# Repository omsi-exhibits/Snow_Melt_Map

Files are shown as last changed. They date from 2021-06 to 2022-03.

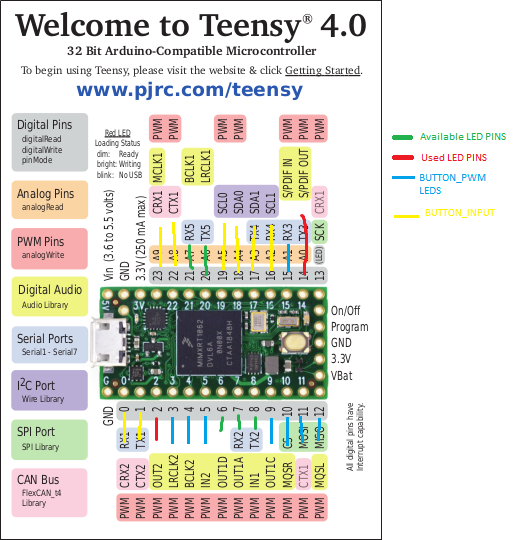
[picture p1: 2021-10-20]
docs/TEENSY_PINOUT_teensy40_card10a_rev2.png

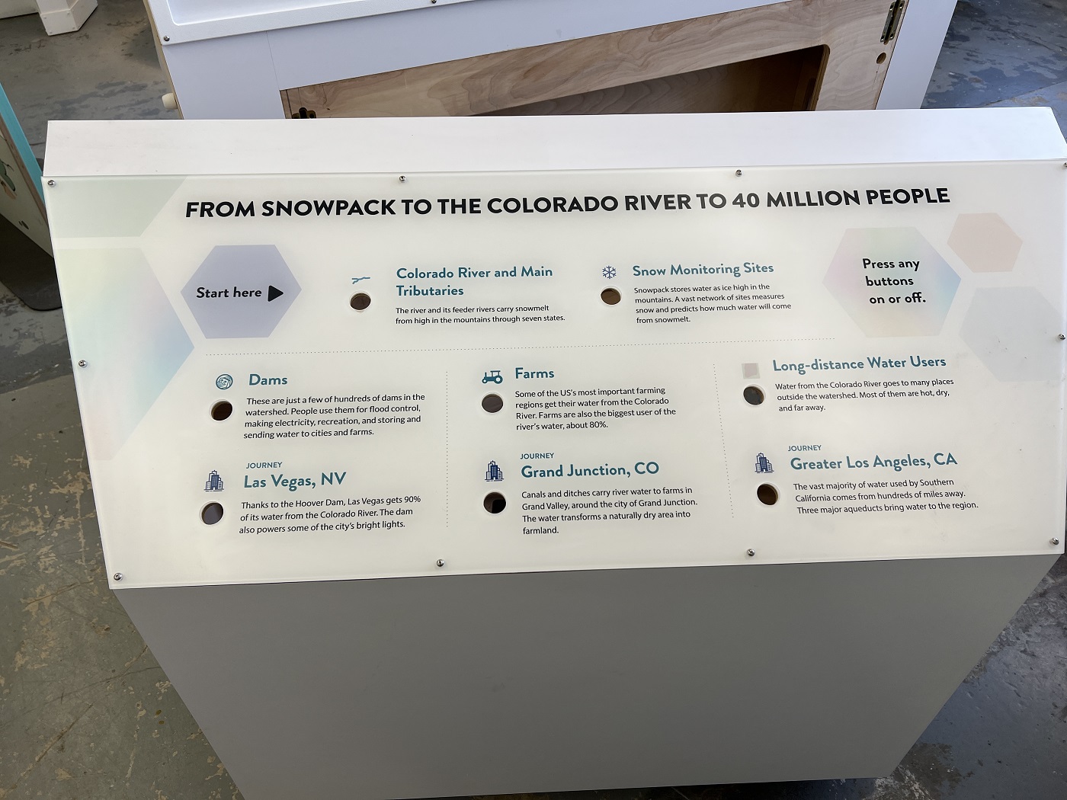
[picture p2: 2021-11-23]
docs/Button Copy.JPG

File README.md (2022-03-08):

# Snow Melt Map Notes
The electronics consist of a custom button controller pcb titled 8x_button_io_board that sends button press
commands to a octoWS2811 adapter with a teensy 4.0 socketed in it. The data sent over serial hand twisted
cable that is around 7 feet long. At a baud rate of 9600. 

addressable rgb led channels with a mcu to control the leds. The current mcu is Adafruit ItsyBitsy M0 express
with a plan to switch to a Teensy 4.0 if more pins or processing power is needed.

## Folder organization
- pcb :: contains eagle pcb files: 8x_button_io_board
- src :: main source code for the led controller 
- docs :: documentation, system diagram, map_led_hole numbering, river_segment_indexes, data sheets
- button_controller_arduino :: code for the button controller
- audio :: audio assets to be used with the wavTrigger board
- examples_tests :: quick tests used to guide prototype direction

## Led Lights
WS2813B  WS2812 code compatible. These leds have 2 data channels incase one led breaks the
backup data channel will be used. This allows the strip to skip a bad led and continue.

## Power Calculations
550 leds 48ma each LED when light at max. The led strings come in 50 led segments. We need power injection every 50 leds at least.
So that is 11 + 1 the end of the strip. 50 Leds at 48mA is 2.4A.

### Total Max Power usage
550 leds * 48mA = 26400mA, If all the leds are on at full brightness.
Power supply is a LRS-200-5 5v 200W output
(Wire Ampacity) [https://en.wikipedia.org/wiki/American_wire_gauge#Tables_of_AWG_wire_sizes]

### Fused Power distro board
(falcon f-8 power distro board) [https://www.pixelcontroller.com/store/accessories/46-f8-distro.html]
There are two power distribution boards with 8 5A fuse holders. The fuse holders take mini blade ATX fuses.

Useful fuse links
(all about fuses for led projects) [https://www.doityourselfchristmas.com/wiki/index.php?title=Power_Supplies#Using_Fuses_and_Fuseholders]
(assorted fuses) [https://www.amazon.com/Bussmann-NO-43-Blade-Tester-Puller/dp/B000DCN9BW]
(fuse holder board mount) [https://www.keyelco.com/product.cfm/Mini-Auto-Fuse-Holders/3544-2/product_id/1376]
(fuse holder mini ATM) [https://www.digikey.com/en/products/detail/keystone-electronics/3568/2137306]

# SNOW MELT MAP Button Target Areas
// Button 1 - Colorado R. & Tributaries
// --- R14 - R34
// Button 2 - Snow Monitoring Sites
// Button 3 - Dams (7)
// Button 4 - Los Vegas City, Dams, and river segments feeding Los Vegas. 
// --- R14 - R30 light up & 4 Dams (Lighting up Damns seems wrong, but maybe okay)
// Button 5 - Farms
// Button 6 - Grand Junction City, Dam, and rivers to the right of the city leading into it
// --- R21b (sub segment) (0-12leds) & R22, Dam
// Button 7 - Greater Los Angeles water supply
// --- Aqueducts too
// --- All river supply. exclude R34
// Button 8 -  (Long-distance water users) Outside Colorado r. Watershed
// --- All Water supply areas.

Once a button is pressed  - Only 1 button may be active at a time.
UI - dim all the currently lit segments and lights then activate what was pressed
Good opportunity for a fade in and fade out sound.

If the on button is pressed it turns the feature off.
If left on after a set time it can return to attractor mode. 

## Programing Notes
LedSegment defines a segment of leds, and their connection point to others.
LedRegion collects LedSegments and has state. The LedRegion can be interacted with.
- TurnedOn, TurnedOff, RiverOn, RiverOff.
- LedModule(Segment) that are for the Dams, etc. Should not store color data in their object.

## FastLED notes:
Colors are always dimmed down by a fraction. The dimming fraction is expressed in 256ths, so if you wanted to dim a color down by 25% of its current brightness, you first have to express that in 256ths. In this case, 25% = 64/256.
```cpp
  // Dim a color by 25% (64/256ths)
  // using "video" scaling, meaning: never fading to full black
  leds[i].fadeLightBy( 64 );
```
The library also provides a function that lets you 'clamp' each of the RGB channels to be within given minimums and maximums. 

Blending colors amountOfP2 is 0 - 255. 128 is 50% 255 is 100 color p2.
```cpp 
CRGB 	blend (const CRGB &p1, const CRGB &p2, fract8 amountOfP2)
```

## Hardware Purchased:
[WS2813 LEDs from raywu](https://www.aliexpress.com/item/32733155461.html)
[Aliexpress Neopixel store - Ray Wu](https://www.aliexpress.com/store/701799?spm=a2g0o.detail.1000002.2.75cff4f3j9F8uI)
LRS-200-5

## LED quality testing
I have determined that the last batch of hardware had some defects that likely were contributing to the intermittent problems
with leds flickering and possible temperature based issues.
We ordered more led strands to try to solve the issue. This time we got about 2x the leds we will need incase we run into the
same issues and need to pick the best leds from the pack.

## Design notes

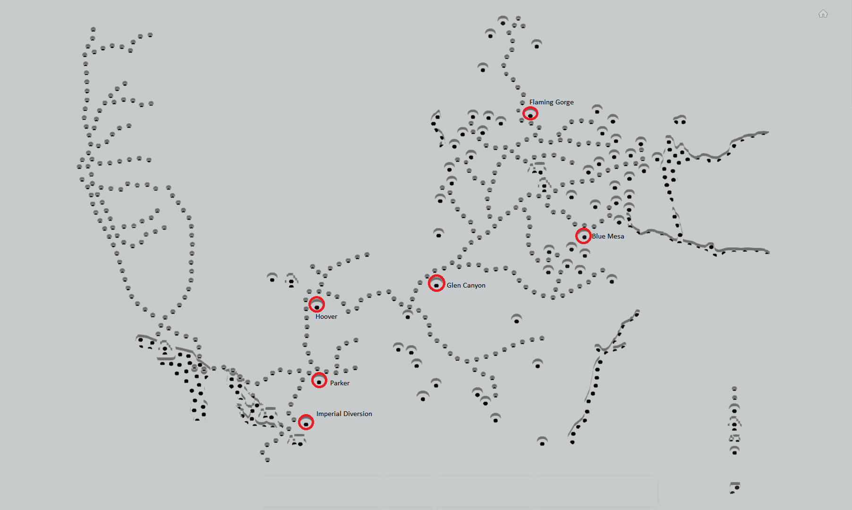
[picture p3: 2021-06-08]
docs/Map_LED_Holes_Dams.png

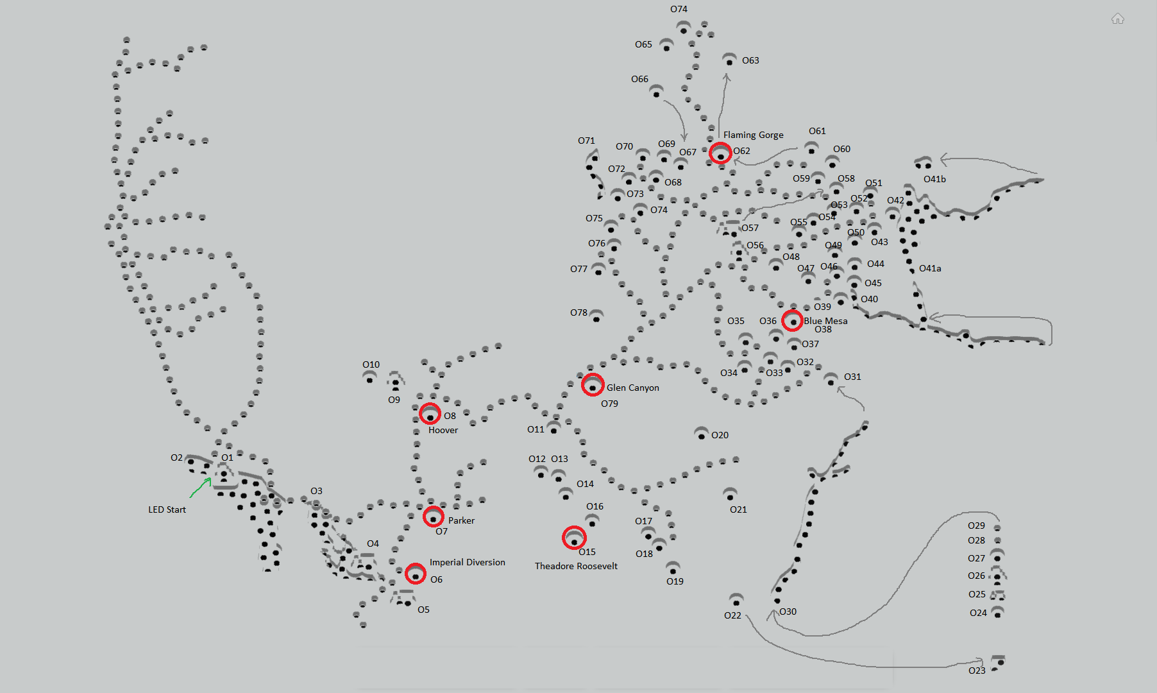
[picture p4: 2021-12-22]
docs/Map_LED_Holes_Dams_and_Rest.png

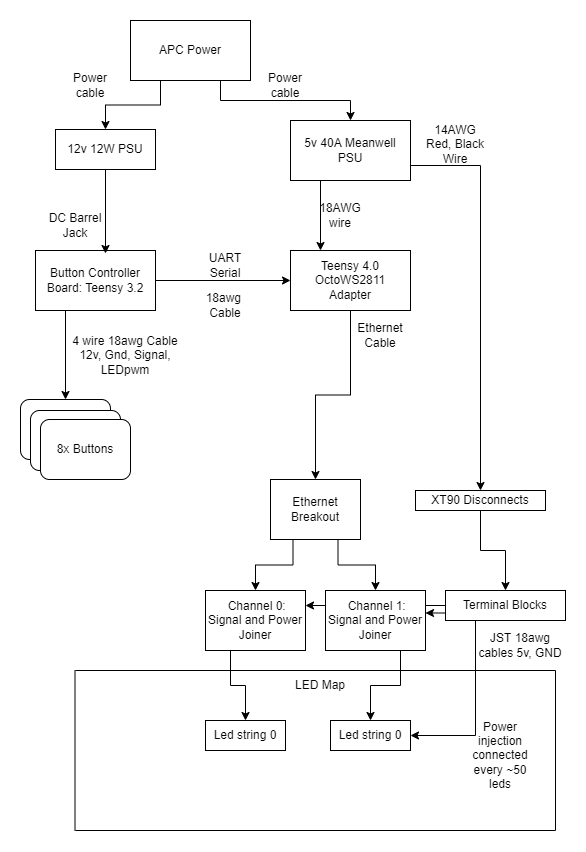
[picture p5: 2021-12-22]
docs/System Diagram.png

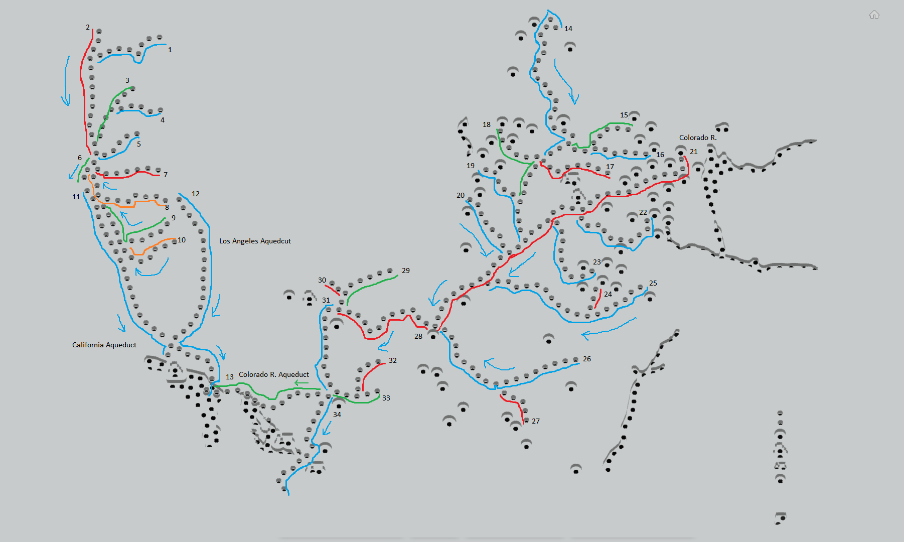
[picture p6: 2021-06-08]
docs/Map_LED_Holes_Rivers_Numbered.png

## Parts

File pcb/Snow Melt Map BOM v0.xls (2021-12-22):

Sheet: Bom
Project Name: Brain Basics | Electronics
 | Bill of Materials
ITEM | DESCRIPTION | Qty/Unit | QTY Total | UNIT PRICE | SUBTOTAL | Link | Notes
Microcontroller | Adafruit itsybitsy 32u4 5v 16mhz | 1 | 4 | $9.95 | $39.80 | https://www.digikey.com/short/zjwf45 | Ordered
12v Power Supply | LRS-100-12 AC to DC 12V 8.5A | 1 | 4 | $18.56 | $74.24 | https://www.digikey.com/products/en?keywords=LRS-100-12 | Ordered
LED strips | 5m White LED Strip Light - Radiant Series LED Tape Light – 12V, 10mm width |  | 3 | $49.95 | $149.85 | https://www.superbrightleds.com/moreinfo/flexible-led-strip-lights/5m-white-led-strip-light-radiant-series-led-tape-light-12v24v-ip20/5147/11527/ | Ordered
LED strip channels | 11Meters needed, OMSI stock is enough |  | 0 | $67.01 | $0.00 | https://www.amazon.com/hunhun-Aluminum-Mounting-Installations-Installation/dp/B07F923CXW | Omsi stock
LED strip channel clips | Clips to hold aluminum channel |  | 2 | $10.00 | $20.00 | https://www.amazon.com/15-Pack-Mounting-Aluminum-Channel-channel/dp/B07886RKNV | Ordered
Jumbo White Button | JUMBO IPB WHITE CLR CAP 14V161 LMP .250 MS W/LOCKING LMPHLDR |  | 3 | $9.95 | $29.85 | https://www.digikey.com/products/en?mpart=1187&v=1528 | Ordered
Large Red Button | RED LARGE 60mm ROUND IPB LAMP W/ .250 MICROSWITCH #161 |  | 2 | $5.95 | $11.90 | https://www.digikey.com/products/en?mpart=1190&v=1528 | Ordered
Audio Board – Wav Trigger | Wav Trig WIG-13660 |  | 3 | $51.95 | $155.85 | https://www.digikey.com/product-detail/en/sparkfun-electronics/WIG-13660/1568-1115-ND/5318757 | Ordered
Audio Amplifier | Lepy LP-2020A |  | 3 | $24.39 | $73.17 | https://www.amazon.com/Lepy-LP-2020A-Digital-Amplifier-Stereo/dp/B00C2P61FO | Ordered
Audio Cable | 3.5mm standard aux cable |  | 3 | $2.43 | $7.29 | https://www.digikey.com/product-detail/en/cnc-tech/770-10040-00100/1175-1449-ND/3828718 | Ordered
Audio Speaker | Poly-Planar MA3013G Round Flush Mount Speaker Pair, Gray, 3-Inch |  | 3 | $41.00 | $123.00 | https://www.amazon.com/Poly-Planar-3-Inch-Round-Flush-Speakers/dp/B00197V836 | Ordered
SD Card | SD card for audio board – pack of 5 |  | 1 | $22.65 | $22.65 | https://www.amazon.com/Pack-SanDisk-Memory-SDSDUNB-016G-GN3IN-Wholesale/dp/B01IMKEMC6?cv_ct_cx=sd+card | Ordered
Smart Tint Film |  |  | 1 |  | $0.00
Smart Tint Film Power supply |  |  | 1 |  | $0.00
Custom PCB | Custom PCB set of 5 |  | 1 | $50.00 | $50.00
PCB enclosure | From aliexpress - ~1month shipping AK-P-25 PLC – set of 4 |  | 1 | $35.33 | $35.33 | https://www.aliexpress.com/item/32868993859.html | Ordered 9-15ish-20
PCB components (Estimate) |  |  | 1 | $100.00 | $100.00
 |  |  |  |  | $853.13

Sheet: PCB BOM
Project Name: Snow Melt Map | Ver 0 | Updated 11-8-21 |  | Electronics
 |  |  |  | PCB Bill of Materials
ITEM | Designator | Value | Part Num | DESCRIPTION | Qty/Unit | QTY Total | UNIT PRICE | SUBTOTAL | Link | Purchase State | Notes
Power Jack | 12VOLT | x |  | DC Power Jack PTH | 1
Capacitor | C2 | 1000uF 35V | 493-1065-ND (https://www.digikey.com/en/products/detail/nichicon/UVR1E102MPD/588806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) |  | 1 |  |  |  | https://www.digikey.com/en/products/detail/nichicon/UVR1E102MPD/588806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 | omsi stock
Capacitor | C3 | 100uF 35V | UVR1E101MED (https://www.digikey.com/en/products/detail/nichicon/UVR1E101MED/588802) |  | 1 |  |  |  | https://www.digikey.com/en/products/detail/nichicon/UVR1E101MED/588802
Capacitor | C4 | 10uF 35V |  |  | 1 |  |  |  | https://www.digikey.com/en/products/detail/nichicon/UVR1E101MED/588802
LED | D1, D2 | LED Red | LTST-C150CKT (https://www.digikey.com/product-detail/en/lite-on-inc/LTST-C150CKT/160-1167-1-ND/269239) | 1206 SMT LED | 2 |  |  |  | LTST-C150CKT (https://www.digikey.com/product-detail/en/lite-on-inc/LTST-C150CKT/160-1167-1-ND/269239)
LED | D3, D4, D5, D6, D7, D8, D9, D10 | LED Green | LTST-C230GKT | 1206 SMT LED | 8
Mosfet Nch | Q2, Q4, Q5, Q6, Q7, Q8, Q9, Q10 | IRLML6344TRPBF | NCH-IRLML6344TRPBF | SOT23-3 Nch Mosfet | 8 |  |  |  | https://www.mouser.com/ProductDetail/Infineon-IR/IRLML6344TRPBF
Resistor | R3, R4, R8, R11, R21, R22, R26, R29, R31, R32, R36, R39, R41, R42, R46, R49 | 10k |  | Resistor 0805 | 16 |  |  |  |  | omsi stock
Resistor | R9, R12, R27, R30, R37, R40, R47, R50 | 100 |  | Resistor 0805 | 8 |  |  |  |  | omsi stock
Resistor | R5, R6, R7, R10, R23, R24, R25, R28, R33, R34, R35, R38, R43, R44, R45, R48 | 220 |  | Resistor 0805 | 16 |  |  |  |  | omsi stock
Resistor | R1 | 340 |  | Resistor 0805 | 1 |  |  |  |  | omsi stock
Resistor | R2 | 600 |  | Resistor 0805 | 1 |  |  |  |  | omsi stock
Power Converter 5V | U2 | R-78E5.0-1.0 | R-78E5.0-1.0 | Recom Power 5V 1A DC/ DC Converter | 1
Microcontroller 3.3V | U$1 | Teensy 3.2 |  |  | 1 |  | $20.00
Opto-Isolator | U1, U3, U4, U5 | ILD213T | ILD213T | Dual Channel Phototransistor Optocoupler | 4
Phoenix Connector Block | X1 | MSTBA3 |  | TERM BLOCK PLUG 3POS STR 5.08MM |  |  |  |  |  | omsi stock
Phoenix Connector Block | X2 | MSTBA4 |  | TERM BLOCK PLUG 4POS STR 5.08MM |  |  |  |  |  | omsi stock
Phoenix Connector Header | J7, J8, J10, J11, J13, J14, J16, J17 | CONN_043.5MM_RA | 1844236 | TERM BLOCK HDR 4POS STR 3.5MM |  |  | $1.86 |  | https://www.digikey.com/en/products/detail/phoenix-contact/1844236/349197
Phoenix Connector Plug | x | x | 1840382 | TERM BLOCK PLUG 4POS STR 3.5MM |  |  | $5.26 |  | https://www.digikey.com/en/products/detail/phoenix-contact/1840382/349179
Power Supply |  | 12v 1A |  | 12v 1A 2.1 ID x 5.5 OD | 1 | 1 | $13.00 |  | https://www.digikey.com/en/products/detail/cui-inc/SWI12-12-N-P5R/5287240 | omsi stock
Enclosure |  |  | SZMOK AK-P-25 Enclosure |  |  |  |  |  | https://www.aliexpress.com/item/32868993859.html
Screws |  |  |  | #4 1/2” screws w/ lock washer |  |  |  |  |  | omsi stock

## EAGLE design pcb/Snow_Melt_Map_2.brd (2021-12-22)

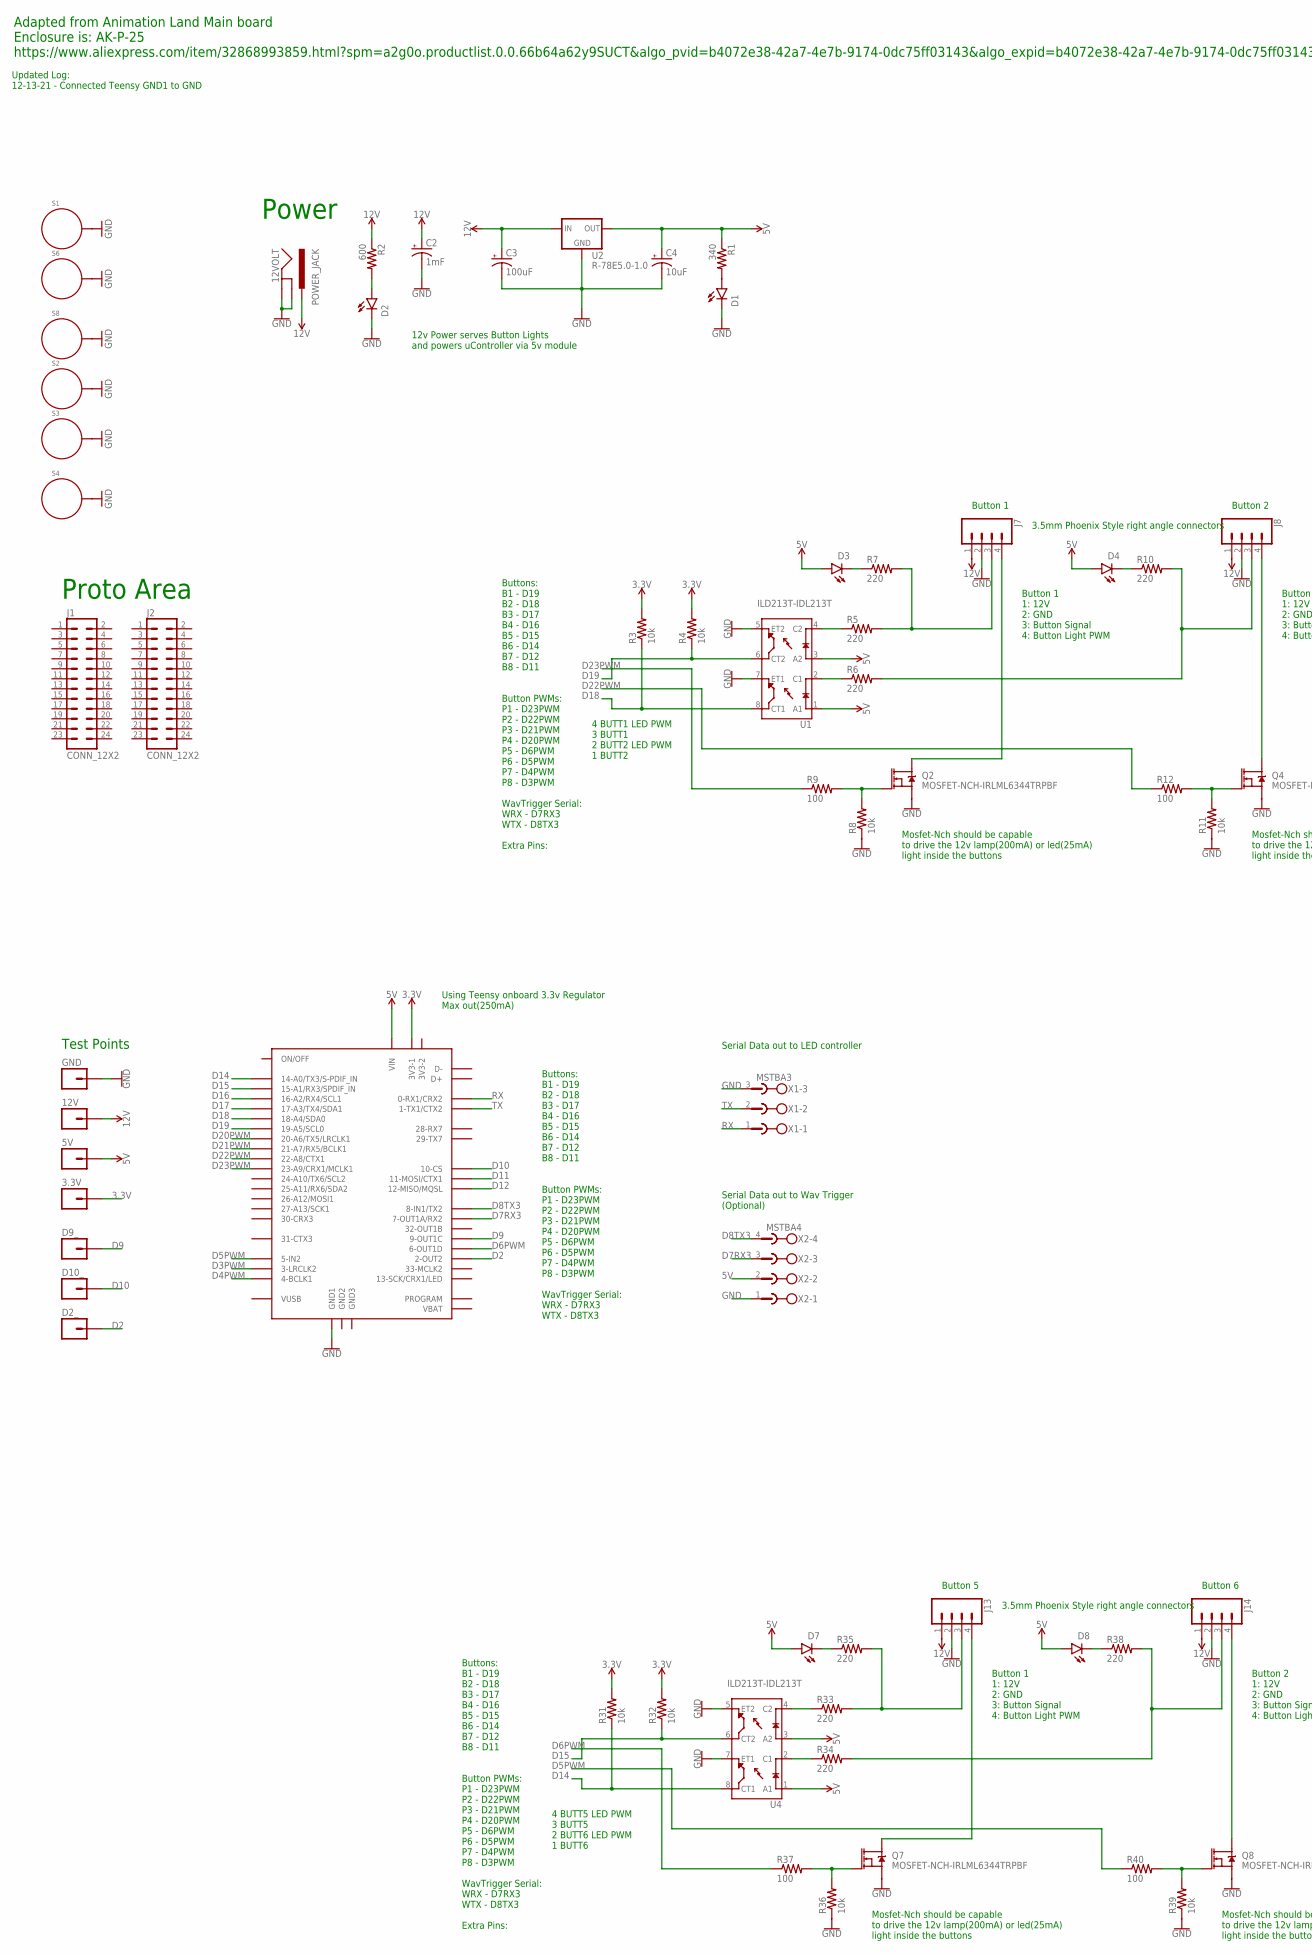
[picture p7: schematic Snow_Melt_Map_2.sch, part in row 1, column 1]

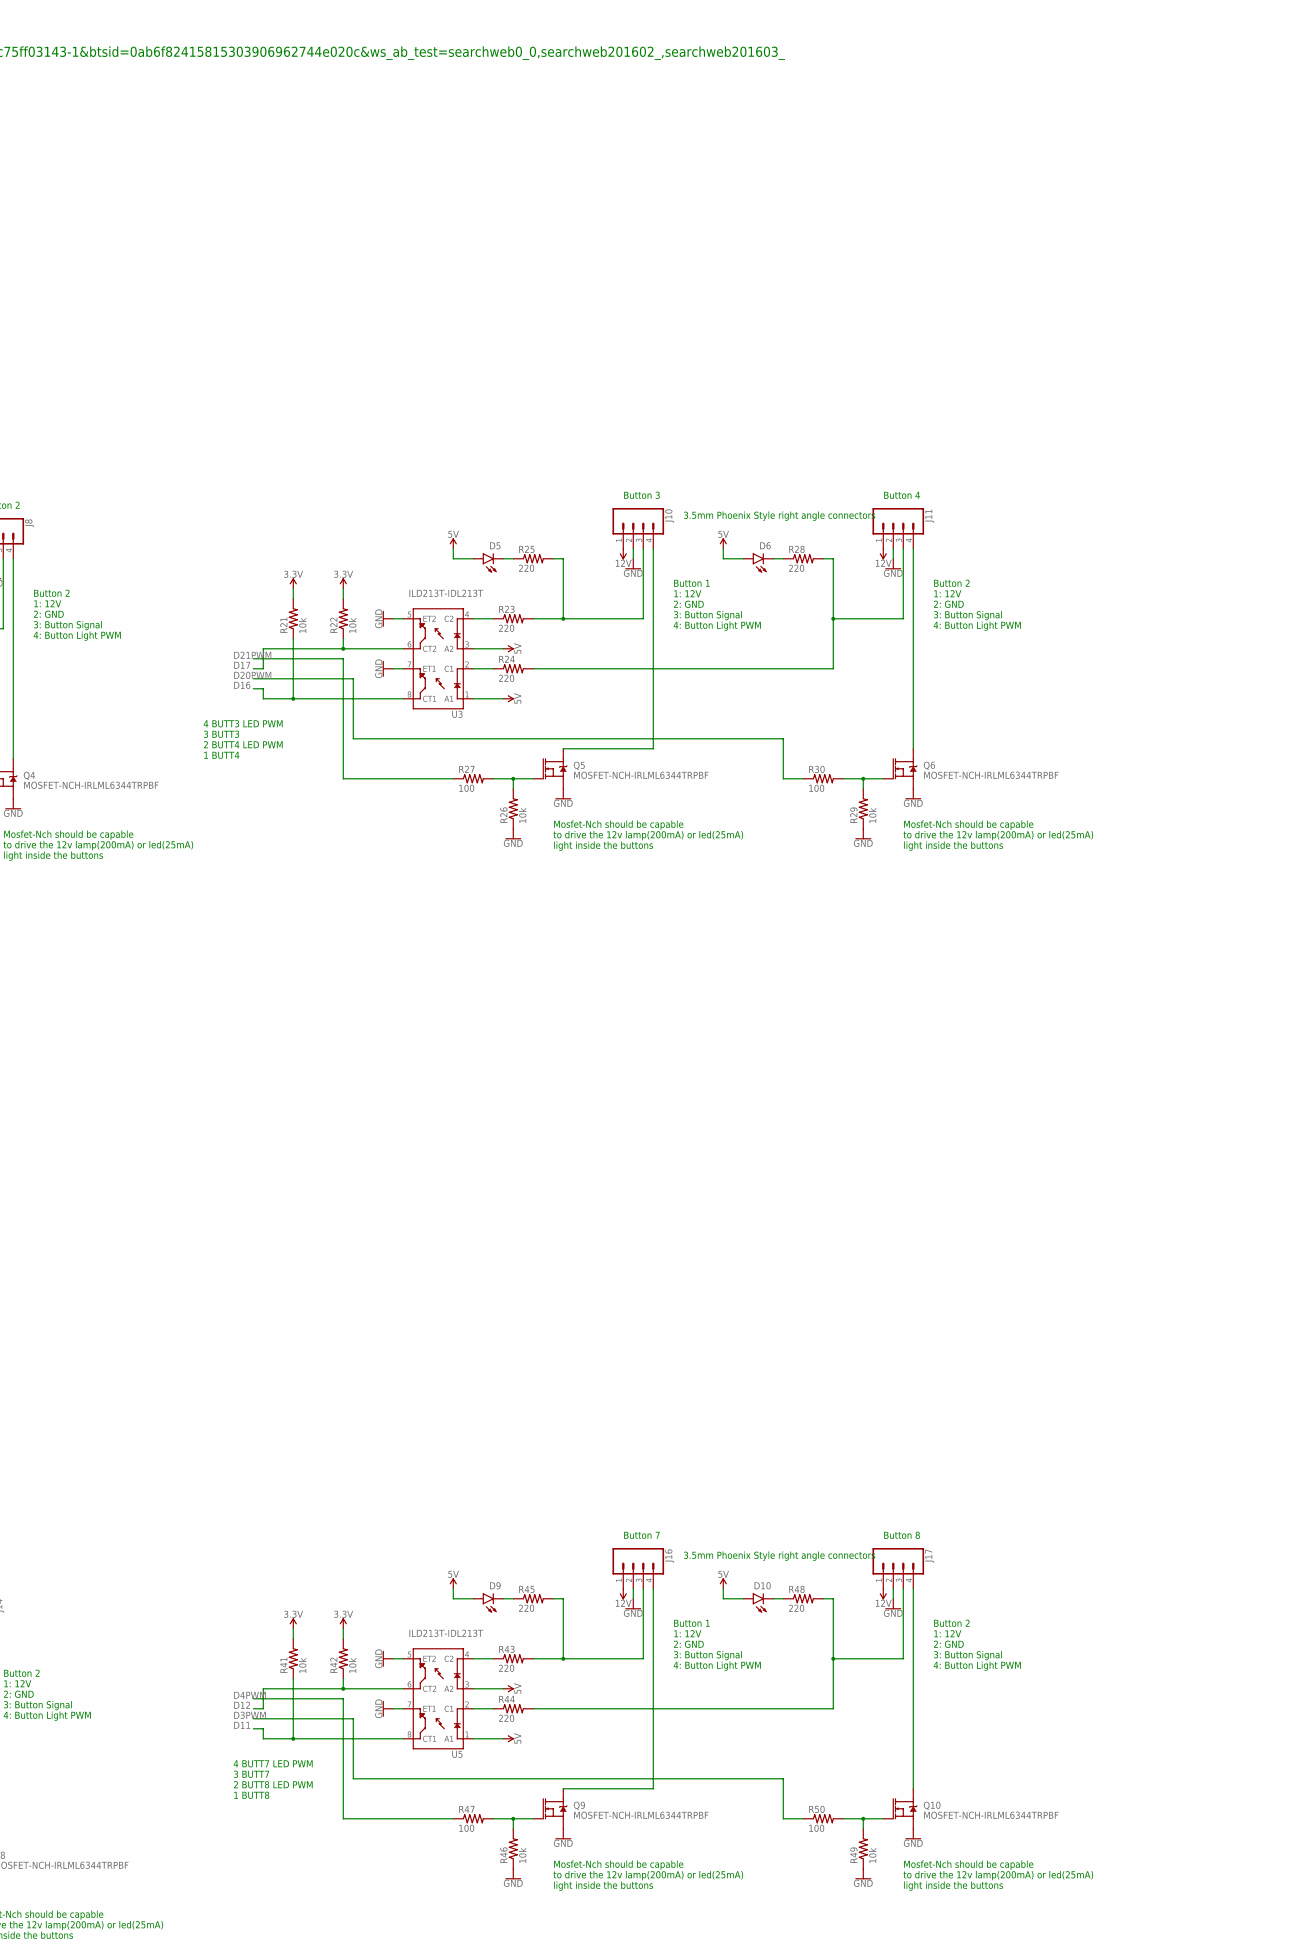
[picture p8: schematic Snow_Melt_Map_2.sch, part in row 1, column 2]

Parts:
3.3V, 5V, 12V: M01PTH; 1X01
12VOLT: POWER_JACK; POWER_JACK_PTH
C2: 1mF; CPOL-RADIAL-5MM-10MM
C3: 100uF; CPOL-RADIAL-2.5MM-6.5MM
C4: 10uF; CPOL-RADIAL-2.5MM-5MM-KIT
D1, D2, D3, D4, D5, D6, D7, D8, D9, D10: RED; LED-1206
D2_, D9_, D10_: M01PTH; 1X01
GND: M01PTH; 1X01
J1, J2: CONN_12X2; 2X12
J7, J8, J10, J11, J13, J14, J16, J17: CONN_043.5MM_RA; 1X04_3.5MM_RA
Q2, Q4, Q5, Q6, Q7, Q8, Q9, Q10: MOSFET-NCH-IRLML6344TRPBF; SOT23-3
R1: 340; R0805
R2: 600; R0805
R3, R4, R8, R11, R21, R22, R26, R29, R31, R32, R36, R39, R41, R42, R46, R49: 10k; R0805
R5, R6, R7, R10, R23, R24, R25, R28, R33, R34, R35, R38, R43, R44, R45, R48: 220; R0805
R9, R12, R27, R30, R37, R40, R47, R50: 100; R0805
S1, S2, S3, S4, S6, S8: STANDOFF_ELECTRICAL5-32; STANDOFF_ELECTRICAL_5_32
U1, U3, U4, U5: ILD213T-IDL213T; SO08
U2: R-78E5.0-1.0; DC-DC_CONVERTER_78XX
U$1: TEENSY40
X1: MSTBA3
X2: MSTBA4

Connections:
3.3V: 3.3V.1, R3.2, R4.2, R21.2, R22.2, R31.2, R32.2, R41.2, R42.2, U$1.3V3-1
5V: 5V.1, C4.1 (+), D3.A, D4.A, D5.A, D6.A, D7.A, D8.A, D9.A, D10.A, R1.1, U1.1 (A1), U1.3 (A2), U2.VOUT (OUT), U3.1 (A1), U3.3 (A2), U4.1 (A1), U4.3 (A2), U5.1 (A1), U5.3 (A2), U$1.VIN, X2.2
12V: 12V.1, 12VOLT.PWR, C2.+, C3.1 (+), J7.1, J8.1, J10.1, J11.1, J13.1, J14.1, J16.1, J17.1, R2.1, U2.VIN (IN)
D2: D2_.1, U$1.2-OUT2
D3PWM: R50.1, U$1.3-LRCLK2
D4PWM: R47.1, U$1.4-BCLK2 (4-BCLK1)
D5PWM: R40.1, U$1.5-IN2
D6PWM: R37.1, U$1.6-OUT1D
D7RX3: U$1.7-RX2/OUT1A (7-OUT1A/RX2), X2.3
D8TX3: U$1.8-TX2/IN1 (8-IN1/TX2), X2.4
D9: D9_.1, U$1.9-OUT1C
D10: D10_.1, U$1.10-CS/MQSR (10-CS)
D11: R41.1, U5.8 (CT1), U$1.11-MOSI/CTX1
D12: R42.1, U5.6 (CT2), U$1.12-MIO/MQSL (12-MISO/MQSL)
D14: R31.1, U4.8 (CT1), U$1.14-A0/TX3/S-PFI_OUT (14-A0/TX3/S-PDIF_IN)
D15: R32.1, U4.6 (CT2), U$1.15-A1/RX3/S-PDIF_IN (15-A1/RX3/SPDIF_IN)
D16: R21.1, U3.8 (CT1), U$1.16-A2/RX4/SCL1
D17: R22.1, U3.6 (CT2), U$1.17-A3/TX4/SDA1
D18: R3.1, U1.8 (CT1), U$1.18-A4/SDA0
D19: R4.1, U1.6 (CT2), U$1.19-A5/SCL0
D20PWM: R30.1, U$1.20-A6/TX5/LRCLK1
D21PWM: R27.1, U$1.21-A7/RX5/BCLK1
D22PWM: R12.1, U$1.22-A8/CTX1
D23PWM: R9.1, U$1.23-A9/CRX1/CCLK1 (23-A9/CRX1/MCLK1)
GND: 12VOLT.GND, 12VOLT.GNDBREAK, C2.-, C3.2 (-), C4.2 (-), D1.C, D2.C, GND.1, J7.2, J8.2, J10.2, J11.2, J13.2, J14.2, J16.2, J17.2, Q2.2 (S), Q4.2 (S), Q5.2 (S), Q6.2 (S), Q7.2 (S), Q8.2 (S), Q9.2 (S), Q10.2 (S), R8.1, R11.1, R26.1, R29.1, R36.1, R39.1, R46.1, R49.1, S1.P1, S2.P1, S3.P1, S4.P1, S6.P1, S8.P1, U1.5 (ET2), U1.7 (ET1), U2.GND, U3.5 (ET2), U3.7 (ET1), U4.5 (ET2), U4.7 (ET1), U5.5 (ET2), U5.7 (ET1), U$1.GND1, X1.3, X2.1
unnamed: D1.A, R1.2
unnamed: D2.A, R2.2
unnamed: J7.3, R5.2, R7.2
unnamed: D3.C, R7.1
unnamed: R5.1, U1.4 (C2)
unnamed: R6.1, U1.2 (C1)
unnamed: Q2.1 (G), R8.2, R9.2
unnamed: J7.4, Q2.3 (D)
unnamed: J8.3, R6.2, R10.2
unnamed: D4.C, R10.1
unnamed: Q4.1 (G), R11.2, R12.2
unnamed: J8.4, Q4.3 (D)
unnamed: J10.3, R23.2, R25.2
unnamed: D5.C, R25.1
unnamed: R23.1, U3.4 (C2)
unnamed: R24.1, U3.2 (C1)
unnamed: Q5.1 (G), R26.2, R27.2
unnamed: J10.4, Q5.3 (D)
unnamed: J11.3, R24.2, R28.2
unnamed: D6.C, R28.1
unnamed: Q6.1 (G), R29.2, R30.2
unnamed: J11.4, Q6.3 (D)
unnamed: J13.3, R33.2, R35.2
unnamed: D7.C, R35.1
unnamed: R33.1, U4.4 (C2)
unnamed: R34.1, U4.2 (C1)
unnamed: Q7.1 (G), R36.2, R37.2
unnamed: J13.4, Q7.3 (D)
unnamed: J14.3, R34.2, R38.2
unnamed: D8.C, R38.1
unnamed: Q8.1 (G), R39.2, R40.2
unnamed: J14.4, Q8.3 (D)
unnamed: J16.3, R43.2, R45.2
unnamed: D9.C, R45.1
unnamed: R43.1, U5.4 (C2)
unnamed: R44.1, U5.2 (C1)
unnamed: Q9.1 (G), R46.2, R47.2
unnamed: J16.4, Q9.3 (D)
unnamed: J17.3, R44.2, R48.2
unnamed: D10.C, R48.1
unnamed: Q10.1 (G), R49.2, R50.2
unnamed: J17.4, Q10.3 (D)
RX: U$1.0-RX1 (0-RX1/CRX2), X1.1
TX: U$1.1-TX1 (1-TX1/CTX2), X1.2

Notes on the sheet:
Adapted from Animation Land Main board Enclosure is: AK-P-25 https://www.aliexpress.com/item/32868993859.html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…
Proto Area
Mosfet-Nch should be capable to drive the 12v lamp(200mA) or led(25mA) light inside the buttons
4 BUTT1 LED PWM 3 BUTT1 2 BUTT2 LED PWM 1 BUTT2
Button 1 1: 12V 2: GND 3: Button Signal 4: Button Light PWM
Button 2 1: 12V 2: GND 3: Button Signal 4: Button Light PWM
3.5mm Phoenix Style right angle connectors
Button 1
Button 2
4 BUTT3 LED PWM 3 BUTT3 2 BUTT4 LED PWM 1 BUTT4
Button 3
Button 4
4 BUTT5 LED PWM 3 BUTT5 2 BUTT6 LED PWM 1 BUTT6
Button 5
Button 6
4 BUTT7 LED PWM 3 BUTT7 2 BUTT8 LED PWM 1 BUTT8
Button 7
Button 8
12v Power serves Button Lights and powers uController via 5v module
Power
Buttons: B1 - D19 B2 - D18 B3 - D17 B4 - D16 B5 - D15 B6 - D14 B7 - D12 B8 - D11 Button PWMs: P1 - D23PWM P2 - D22PWM P3 - D21PWM P4 - D20PWM P5 - D6PWM P6 - D5PWM P7 - D4PWM P8 - D3PWM WavTrigger Serial: WRX - D7RX3 WTX - D8TX3
Using Teensy onboard 3.3v Regulator Max out(250mA)
Buttons: B1 - D19 B2 - D18 B3 - D17 B4 - D16 B5 - D15 B6 - D14 B7 - D12 B8 - D11 Button PWMs: P1 - D23PWM P2 - D22PWM P3 - D21PWM P4 - D20PWM P5 - D6PWM P6 - D5PWM P7 - D4PWM P8 - D3PWM WavTrigger Serial: WRX - D7RX3 WTX - D8TX3 Extra Pins:
Serial Data out to LED controller
Test Points
Serial Data out to Wav Trigger (Optional)
Updated Log: 12-13-21 - Connected Teensy GND1 to GND

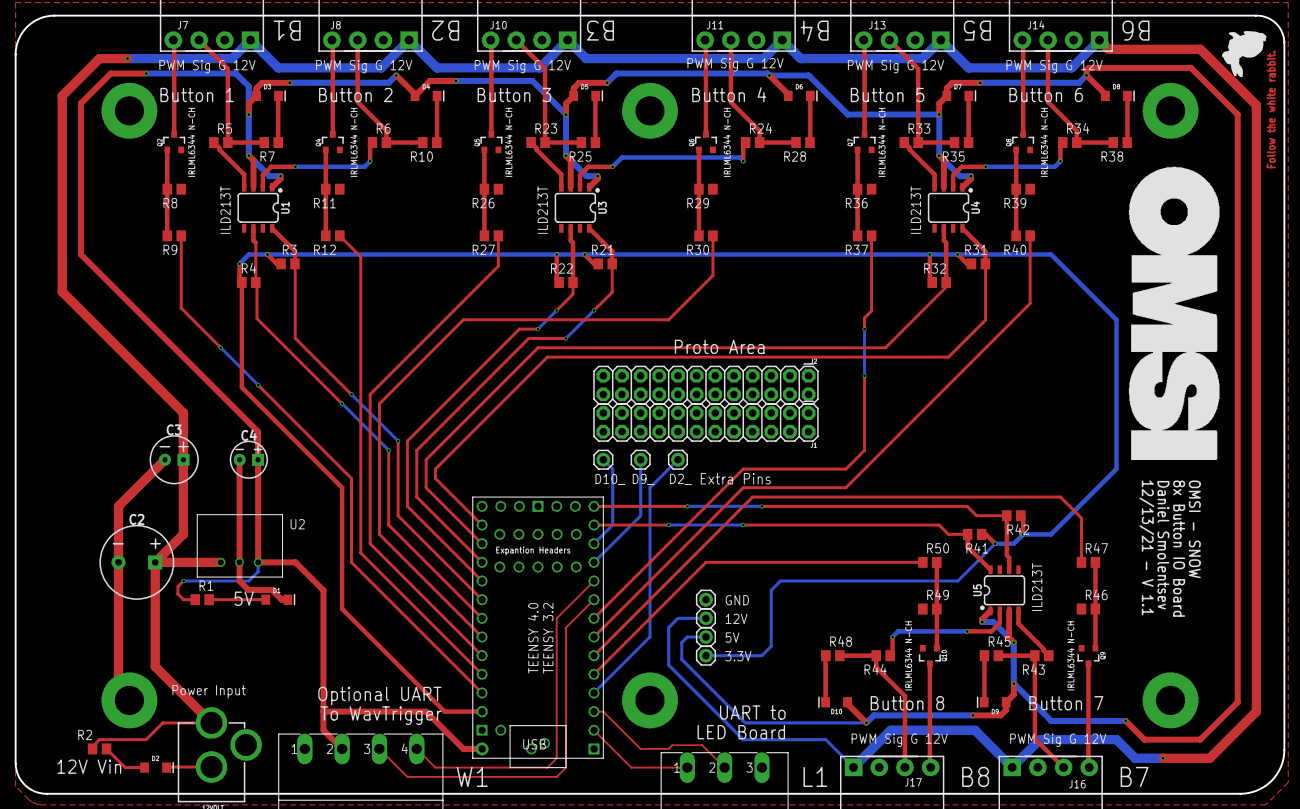
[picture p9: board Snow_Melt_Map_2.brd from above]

Board: 2 copper layers, 172.7 x 105.9 mm, 95 parts (0 on the bottom side), 69 nets.

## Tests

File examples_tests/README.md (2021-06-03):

# Place Arduino ready examples and Tests Here

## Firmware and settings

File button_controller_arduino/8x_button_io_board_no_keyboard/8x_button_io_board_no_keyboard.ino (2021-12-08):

// 8-Button IO Board, based on Vroom by Daniel Smolentsev
// Customized for Snow_Melt_Map By Justin Patrizi 11/18/21
// Updated 11/23/21 - Added Serial1 out 

// * * * * Author * * * * //
// Daniel Smolentsev
// OMSI . 1/12/20

// * * * * Arduino * * * * * * //
// Arduino Version 1.8.9
// Teensy 3.2

// * * * * Libraries Used * * * * * * //
// https://github.com/thomasfredericks/Bounce2
// Arduino Keyboard.h

/*
   This program listens to button inputs and then outputs on Serial1 . 1-8 buttons press a byte with the value of 1-8
   In attractor mode the buttons pulse in unison. Once a button is pressed it will Disable input and dim the led lights for
   the duration a configurable duration. Here set to 100ms. Audio feedback will play on a button press as well.
*/

#define DEBUG 1

#include <Bounce2.h>
//#include <Keyboard.h>
#include "wavTrigger.h"
#include "AudioOut.h"

AudioOut audioOut = AudioOut();

#define BUTTON_1 A5
#define BUTTON_2 A4
#define BUTTON_3 A3
#define BUTTON_4 A2
#define BUTTON_5 A1
#define BUTTON_6 A0
#define BUTTON_7 12
#define BUTTON_8 11

#define BUTTON_1_LED A9
#define BUTTON_2_LED A8
#define BUTTON_3_LED A7
#define BUTTON_4_LED A6
#define BUTTON_5_LED 6
#define BUTTON_6_LED 5
#define BUTTON_7_LED 4
#define BUTTON_8_LED 3

Bounce button1 = Bounce();
Bounce button2 = Bounce();
Bounce button3 = Bounce();
Bounce button4 = Bounce();
Bounce button5 = Bounce();
Bounce button6 = Bounce();
Bounce button7 = Bounce();
Bounce button8 = Bounce();

//////////////////////////////////////////// Button panel /////////////////////////////////////////////////
//
// 1 - Colorado River and Main Tributaries
// 3 - Snow Monitoring Sites
// 4 - Dams
// 5 - Farms
// 6 - Grand Junction City
// 7 - Long-Distance Water Users
// 8 - Los Angeles Water Supply
//
/////////////////////////////////////////////////////////////////////////////////////////////////////////////

int state = 0;
// state 0 - attractor (buttons pulse), state - 1 button pressed, state - 2 wait for video length time

unsigned long videoDelayTimer = 0;
unsigned long pulseDelayTimer = 0;
const unsigned int pulseStepDelay = 20;

unsigned int skewerDelay = 100;
unsigned int skewerSPDelay = 100; //Patrones en la comida
unsigned int beatsDelay = 100;
unsigned int beatsSPDelay = 100; //Ritmos Intermitentes
unsigned int shoesDelay = 100;
unsigned int shoesSPDelay = 100; // Eparajar los Zapatos
unsigned long currentDelay = 0;


unsigned long heartBeatTimer = 0;
boolean heartBeat = false;


int ramp = 0;
const int rampMax = 125;
const int rampMin = 16;
int dimming = 1; // 1 incrase, -1 decrease
const int pressedBrightness = 175;


//* * * * * setup * * * * *//
void setup ()
{
  pinMode(BUTTON_1, INPUT_PULLUP);
  pinMode(BUTTON_2, INPUT_PULLUP);
  pinMode(BUTTON_3, INPUT_PULLUP);
  pinMode(BUTTON_4, INPUT_PULLUP);
  pinMode(BUTTON_5, INPUT_PULLUP);
  pinMode(BUTTON_6, INPUT_PULLUP);
  pinMode(BUTTON_7, INPUT_PULLUP);
  pinMode(BUTTON_8, INPUT_PULLUP);

  pinMode(BUTTON_1_LED, OUTPUT);
  pinMode(BUTTON_2_LED, OUTPUT);
  pinMode(BUTTON_3_LED, OUTPUT);
  pinMode(BUTTON_4_LED, OUTPUT);
  pinMode(BUTTON_5_LED, OUTPUT);
  pinMode(BUTTON_6_LED, OUTPUT);
  pinMode(BUTTON_7_LED, OUTPUT);
  pinMode(BUTTON_8_LED, OUTPUT);


  button1.attach(BUTTON_1);
  button1.interval(50);

  button2.attach(BUTTON_2);
  button2.interval(50);

  button3.attach(BUTTON_3);
  button3.interval(50);

  button4.attach(BUTTON_4);
  button4.interval(50);

  button5.attach(BUTTON_5);
  button5.interval(50);

  button6.attach(BUTTON_6);
  button6.interval(50);

  button7.attach(BUTTON_7);
  button7.interval(50);

  button8.attach(BUTTON_8);
  button8.interval(50);

//Keyboard.begin();

// Serial Out setup to the led controller board.
Serial1.begin(9600);
audioOut.begin();
}  // end of setup

void pulseButtonLeds() {
  if (millis() - pulseDelayTimer >= pulseStepDelay) {
    //pulse button led
    if (ramp >= rampMax) {
      // flip the direction of the dimming
      dimming = -1;
    } else if (ramp <= rampMin ) {
      dimming = 1;
    }
    ramp += dimming;

    analogWrite(BUTTON_1_LED, ramp);
    analogWrite(BUTTON_2_LED, ramp);
    analogWrite(BUTTON_3_LED, ramp);
    analogWrite(BUTTON_4_LED, ramp);
    analogWrite(BUTTON_5_LED, ramp);
    analogWrite(BUTTON_6_LED, ramp);
    analogWrite(BUTTON_7_LED, ramp);
    analogWrite(BUTTON_8_LED, ramp);
    pulseDelayTimer = millis();
  }
}

void dimButtonLeds() {
  analogWrite(BUTTON_1_LED, rampMin);
  analogWrite(BUTTON_2_LED, rampMin);
  analogWrite(BUTTON_3_LED, rampMin);
  analogWrite(BUTTON_4_LED, rampMin);
  analogWrite(BUTTON_5_LED, rampMin);
  analogWrite(BUTTON_6_LED, rampMin);
  analogWrite(BUTTON_7_LED, rampMin);
  analogWrite(BUTTON_8_LED, rampMin);
}

void doButtons() {

  // update button input
  button1.update();
  button2.update();
  button3.update();
  button4.update();
  button5.update();
  button6.update();
  button7.update();
  button8.update();
  // read buttons

  if (button1.fell()) {
#ifdef DEBUG
    Serial.println("1 Button Fell");
#endif
    state = 1;
    videoDelayTimer = millis();
    currentDelay = shoesDelay;
    //Keyboard.write('1');
    analogWrite(BUTTON_1_LED, pressedBrightness);
    Serial1.write(1);
    audioOut.randomizePitch();
    audioOut.playTrack(1);
  }

  if (button2.fell()) {
#ifdef DEBUG
    Serial.println("2 Button Fell");
#endif
    state = 1;
    videoDelayTimer = millis();
    currentDelay = beatsDelay;
    //Keyboard.write('2');
    analogWrite(BUTTON_2_LED, pressedBrightness);
    Serial1.write(2);
    audioOut.randomizePitch();
    audioOut.playTrack(1);
  }

  if (button3.fell()) {
#ifdef DEBUG
    Serial.println("3 Button Fell");
#endif
    state = 1;
    videoDelayTimer = millis();
    currentDelay = skewerDelay;
    //Keyboard.write('3');
    analogWrite(BUTTON_3_LED, pressedBrightness);
    Serial1.write(3);
    audioOut.randomizePitch();
    audioOut.playTrack(1);
  }

  if (button4.fell()) {
#ifdef DEBUG
    Serial.println("4 Button Fell");
#endif
    state = 1;
    videoDelayTimer = millis();
    currentDelay = shoesSPDelay;
    //Keyboard.write('4');
    analogWrite(BUTTON_4_LED, pressedBrightness);
    Serial1.write(4);
    audioOut.randomizePitch();
    audioOut.playTrack(1);
  }

  if (button5.fell()) {
#ifdef DEBUG
    Serial.println("5 Button Fell");
#endif
    state = 1;
    videoDelayTimer = millis();
    currentDelay = beatsSPDelay;
    //Keyboard.write('5');
    analogWrite(BUTTON_5_LED, pressedBrightness);
    Serial1.write(5);
    audioOut.randomizePitch();
    audioOut.playTrack(1);
  }

  if (button6.fell()) {
#ifdef DEBUG
    Serial.println("6 Button Fell");
#endif
    state = 1;
    videoDelayTimer = millis();
    currentDelay = skewerSPDelay;
    //Keyboard.write('6');
    analogWrite(BUTTON_6_LED, pressedBrightness);
    Serial1.write(6);
    audioOut.randomizePitch();
    audioOut.playTrack(1);
  }

  if (button7.fell()) {
#ifdef DEBUG
    Serial.println("7 Button Fell");
#endif
    state = 1;
    videoDelayTimer = millis();
    currentDelay = skewerSPDelay;
    //Keyboard.write('7');
    analogWrite(BUTTON_7_LED, pressedBrightness);
    Serial1.write(7);
    audioOut.randomizePitch();
    audioOut.playTrack(1);
  }

  if (button8.fell()) {
#ifdef DEBUG
    Serial.println("8 Button Fell");
#endif
    state = 1;
    videoDelayTimer = millis();
    currentDelay = skewerSPDelay;
    //Keyboard.write('8');
    analogWrite(BUTTON_8_LED, pressedBrightness);
    Serial1.write(8);
    audioOut.randomizePitch();
    audioOut.playTrack(1);
  }
}

void loop() {
  audioOut.update();

  // pulse button leds
  // ramp up ledstrip brightness
  if (state == 0) {
    pulseButtonLeds();
    doButtons();
  } else if (state == 1) {
    // do nothing this loop to flash button on being pressed
    // transition to state 2
    delay(100);
    state = 2;
  } else  if (state == 2) {
    dimButtonLeds();
    // return to state 0 after 4 secs
    if (millis() - videoDelayTimer > currentDelay) {
      state = 0;
    }

  }


  if (millis() - heartBeatTimer > 500) {
    if (heartBeat) {
      digitalWrite(13, HIGH);
    } else {
      digitalWrite(13, LOW);
    }
    heartBeat = !heartBeat;
    heartBeatTimer = millis();
  }

 
}

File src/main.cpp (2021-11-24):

/* Snow Melt Map - Proof of Concept 
 * 
 */

#include <FastLED.h>
#include "HeartBeat.h"
//#include "hw.h"
#include "hw_teensy.h"
#include "LedModule.h"
#include "LedSegment.h"
#include "LedMap.h"
#include "SerialReader.h"

HeartBeat heartBeat = HeartBeat(13); // pin
LedMap ledMap = LedMap();

// Input object
SerialReader serialInput = SerialReader();


unsigned long attractorTimer = 0;
unsigned long attractorTimeOut = 10000; // 10 seconds
enum STATE { ATTRACTOR, LISTENING, IDLE };
int mainState = LISTENING; // 0 - attractor, 1 - listening to buttons

bool riverToggle = true;
unsigned long riverTimer = 0;
unsigned long riverTimeStep = 2200;

/********************** function definitions *************************/

/************************* SETUP ***********************/
void setup() {
  //heartbeat led
  //Serial.begin(9600);
  pinMode(13,OUTPUT);
  serialInput.begin();
  ledMap.receiveInput(8);
}
void loop() {
  heartBeat.update();

  // Get input from SerialReader 
  serialInput.update();
  int buttonIn = serialInput.getAButton();
  //Serial.print("button rec: ");
  //Serial.println(buttonIn);


  // *********** Main State *************
  if(mainState == ATTRACTOR) {
    if(buttonIn != -1) {
        ledMap.receiveInput(buttonIn);
        attractorTimer = millis();
        mainState = LISTENING;
        Serial.println(F("Entering Listening Mode"));
    } 
  } else if (mainState == LISTENING) {
    if(buttonIn != -1) {
      ledMap.receiveInput(buttonIn);
      Serial.print(F("Trigger ledmap.receiveInput(): "));
      Serial.println(buttonIn);
      attractorTimer = millis();
    } else {
      // else check if enough time has passed to enter attractor mode
      if(millis() - attractorTimer > attractorTimeOut) {
        mainState = ATTRACTOR;
        //enter attractor mode in led map. 
        ledMap.receiveInput(9);
        Serial.println(F("Entering Attractor Mode"));
      }
    }
  }

  // ******************************** update and draw map ***************************
    ledMap.update();
    ledMap.drawLeds();
}

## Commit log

2021-06-03 Initial commit. Proof of concept. Basic DMA Neopixel on pin 12
2021-06-08 Added Holes Map documentation and Segments Indexes spread sheet
    [River_Segments_Indexes.xls]
2021-06-09 Led Segments implemented. Led River Marque animation.
2021-06-10 Multi LedSegment LedModule almost works
2021-06-10 Multi Segment LedModule is working.
2021-06-14 added more leds to the output to troubleshoot
2021-06-14 Seems to work without flickering! Had to add capacitors at power splice points.
2021-06-21 continued power issues, investigation.
    [LedModule.cpp, LedModule.h, main.cpp]
2021-06-24 Sanity. Its working on Teensy 4.0 Octows2811-Top Jack LEDStrip#2
2021-08-05 updated readme with LED quality inspection info
2021-09-02 Trying to get 2 led strings to work at once. only one works
2021-10-20 added non-river ledSegments. Changed city color to orange
2021-10-21 all segments working, river is flowing with basic animations
2021-11-11 LedMap class added .. partially working
2021-11-23 Interactivity is in. Basic Button input. Updated docs. Still a few bugs
    [River_Segments_Indexes_2.xls]
2021-12-08 added all the outside docs and audio and teensy led tests
    [River_Segments_Indexes.xls, River_Segments_Indexes_2.xls]
2021-12-22 fixed snowsite O16 and O15 (dam) switched.
    [River_Segments_Indexes.xls, Snow Melt Map BOM v0.xls, Snow_Melt_Map_2.brd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]
2022-03-08 fixed map key not having correct color for snowsites and dams
    [LedMap.cpp]

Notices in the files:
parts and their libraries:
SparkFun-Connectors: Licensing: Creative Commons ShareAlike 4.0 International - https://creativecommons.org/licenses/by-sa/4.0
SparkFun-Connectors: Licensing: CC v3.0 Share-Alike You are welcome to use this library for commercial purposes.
